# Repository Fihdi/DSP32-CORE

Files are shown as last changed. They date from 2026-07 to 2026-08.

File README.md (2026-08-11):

# DSP32-Core
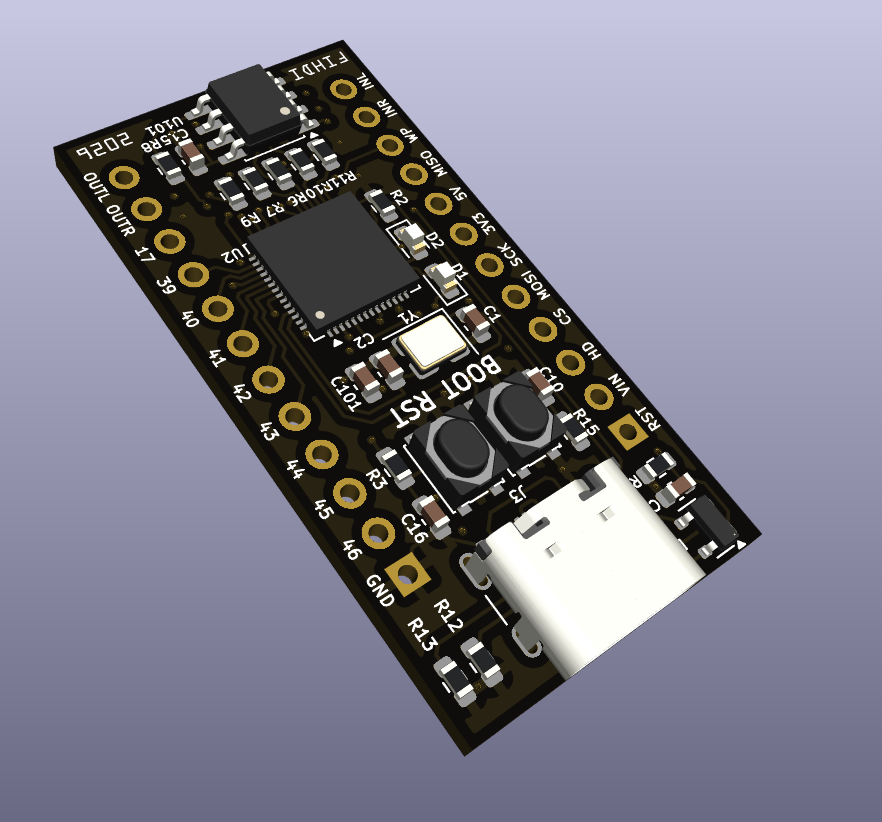
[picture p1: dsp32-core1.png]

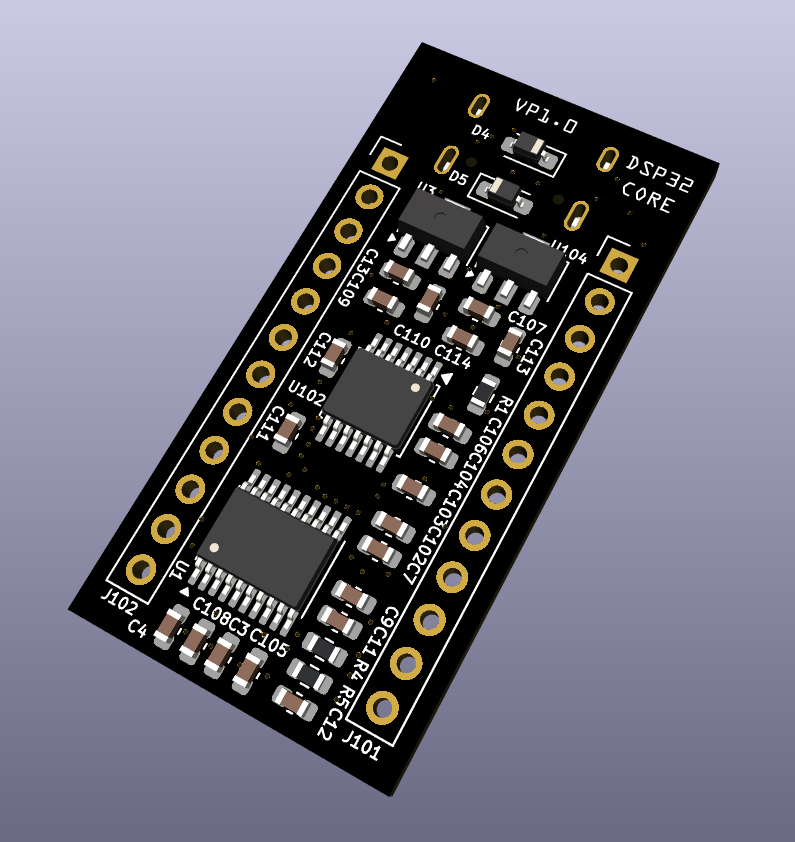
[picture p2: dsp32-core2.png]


DSP32-Core is a small (4cm x 2cm) audio development board based on the ESP32-S3. This board can be used as the core for digital music and audio applications involving synthesizers, samplers, digital effects, sequencers, etc. The SPI interface allows to connect an SD-card to the board and save and replay music and project settings.

# Features
+ Stereo audio in- and output
+ 3.3V and 5V voltage regulator
+ USB and SPI Interface
+ up to 15 GPIO pins
+ PCM1808 ADC
+ PCM5102 DAC.
# Pinout
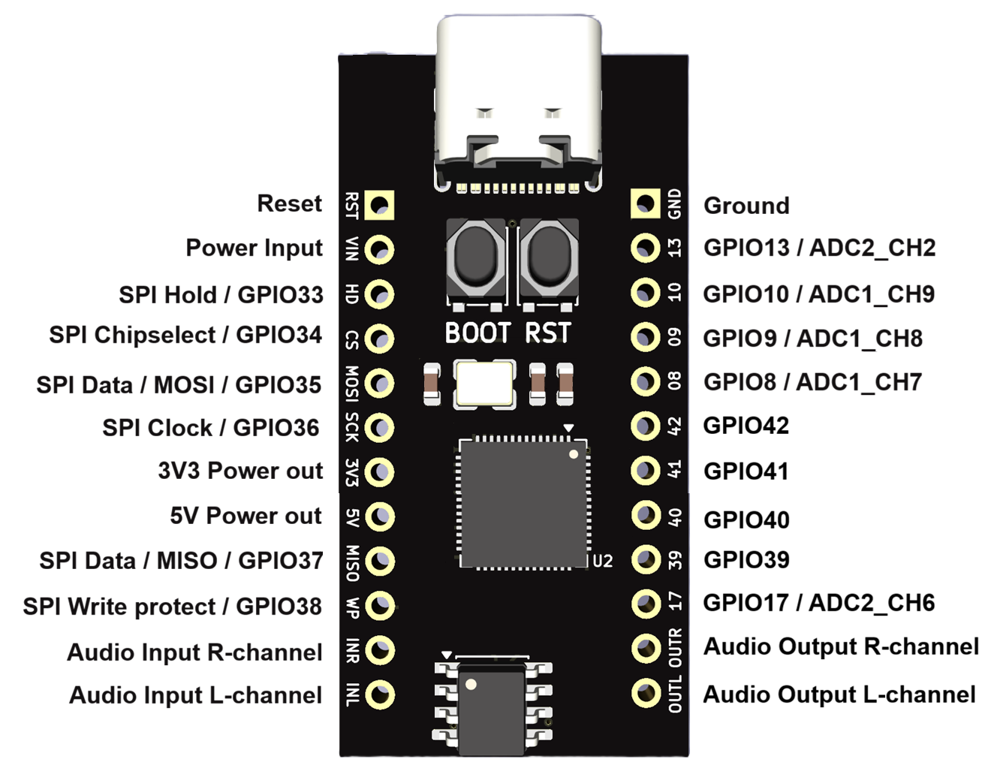
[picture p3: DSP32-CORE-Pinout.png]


PCB fabrication sponsored by [PCBWay](https://pcbway.com). Their excellent PCB assembly service allows the DSP32-CORE to be produced in with every component perfectly soldered. Simply upload the production files like gerbers, position and BOM files and receive your fully assembled audio development board. High PCB quality and good customer service throughout the process makes PCBWay a reliable partner.



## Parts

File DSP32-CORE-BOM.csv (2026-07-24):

Reference | Qty | Value | DNP | Exclude from BOM | Exclude from Board | Footprint | Datasheet
C1,C2 | 2 | 6pF |  |  |  | Capacitor_SMD:C_0603_1608Metric | ~
C3,C4,C13,C105,C107 | 5 | 2u2 |  |  |  | Capacitor_SMD:C_0603_1608Metric | ~
C7,C102,C103,C104 | 4 | 1u |  |  |  | Capacitor_SMD:C_0603_1608Metric | ~
C9,C10,C15,C16,C101,C106,C108,C109,C110,C111,C114 | 11 | 100n |  |  |  | Capacitor_SMD:C_0603_1608Metric | ~
C11,C12 | 2 | 2n2 |  |  |  | Capacitor_SMD:C_0603_1608Metric | ~
C14 | 1 | 4n7 |  |  |  | Capacitor_SMD:C_0603_1608Metric | ~
C112,C113 | 2 | 10u |  |  |  | Capacitor_SMD:C_0603_1608Metric | ~
D1,D2 | 2 | LED |  |  |  | LED_SMD:LED_0603_1608Metric | ~
D4,D5 | 2 | 1N4148 |  |  |  | Diode_SMD:D_SOD-323_HandSoldering | ~
D6 | 1 | PRTR5V0U2X |  |  |  | Package_TO_SOT_SMD:SOT-143 | https://assets.nexperia.com/documents/data-sheet/PRTR5V0U2X.pdf
J3 | 1 | USB_C_Receptacle |  |  |  | Connector_USB:USB_C_Receptacle_GCT_USB4105-xx-A_16P_TopMnt_Horizontal | https://www.usb.org/sites/default/files/documents/usb_type-c.zip
J101,J102 | 2 | Conn_01x12_Pin |  |  |  | Connector_PinHeader_2.54mm:PinHeader_1x12_P2.54mm_Vertical | ~
R1,R2 | 2 | 1k |  |  |  | Resistor_SMD:R_0603_1608Metric | ~
R3,R12,R13,R15 | 4 | 5k1 |  |  |  | Resistor_SMD:R_0603_1608Metric | ~
R4,R5 | 2 | 470R |  |  |  | Resistor_SMD:R_0603_1608Metric | ~
R6,R7,R8,R9,R10,R11 | 6 | 0R |  |  |  | Resistor_SMD:R_0603_1608Metric | ~
R14 | 1 | 1M |  |  |  | Resistor_SMD:R_0603_1608Metric | ~
SW1,SW2 | 2 | SW_Push |  |  |  | Button_Switch_SMD:SW_SPST_PTS810 | ~
U1 | 1 | PCM5102 |  |  |  | Package_SO:TSSOP-20_4.4x6.5mm_P0.65mm | http://www.ti.com/lit/ds/symlink/pcm5102.pdf
U2 | 1 | ESP32-S3 |  |  |  | Package_DFN_QFN:QFN-56-1EP_7x7mm_P0.4mm_EP4x4mm | https://www.espressif.com/sites/default/files/documentation/esp32-s3_datasheet_en.pdf
U3 | 1 | AMS1117-3.3 |  |  |  | Package_TO_SOT_SMD:SOT-89-3 | http://www.advanced-monolithic.com/pdf/ds1117.pdf
U101 | 1 | W25Q128JVS |  |  |  | Package_SO:SOIC-8_5.3x5.3mm_P1.27mm | https://www.winbond.com/resource-files/w25q128jv_dtr%20revc%2003272018%20plus.pdf
U102 | 1 | PCM1808 |  |  |  | Package_SO:TSSOP-14_4.4x5mm_P0.65mm
U104 | 1 | MC78L05_SOT89 |  |  |  | Package_TO_SOT_SMD:SOT-89-3 | https://www.onsemi.com/pub/Collateral/MC78L00A-D.PDF
Y1 | 1 | 40MHz |  |  |  | Crystal:Crystal_SMD_3225-4Pin_3.2x2.5mm | ~

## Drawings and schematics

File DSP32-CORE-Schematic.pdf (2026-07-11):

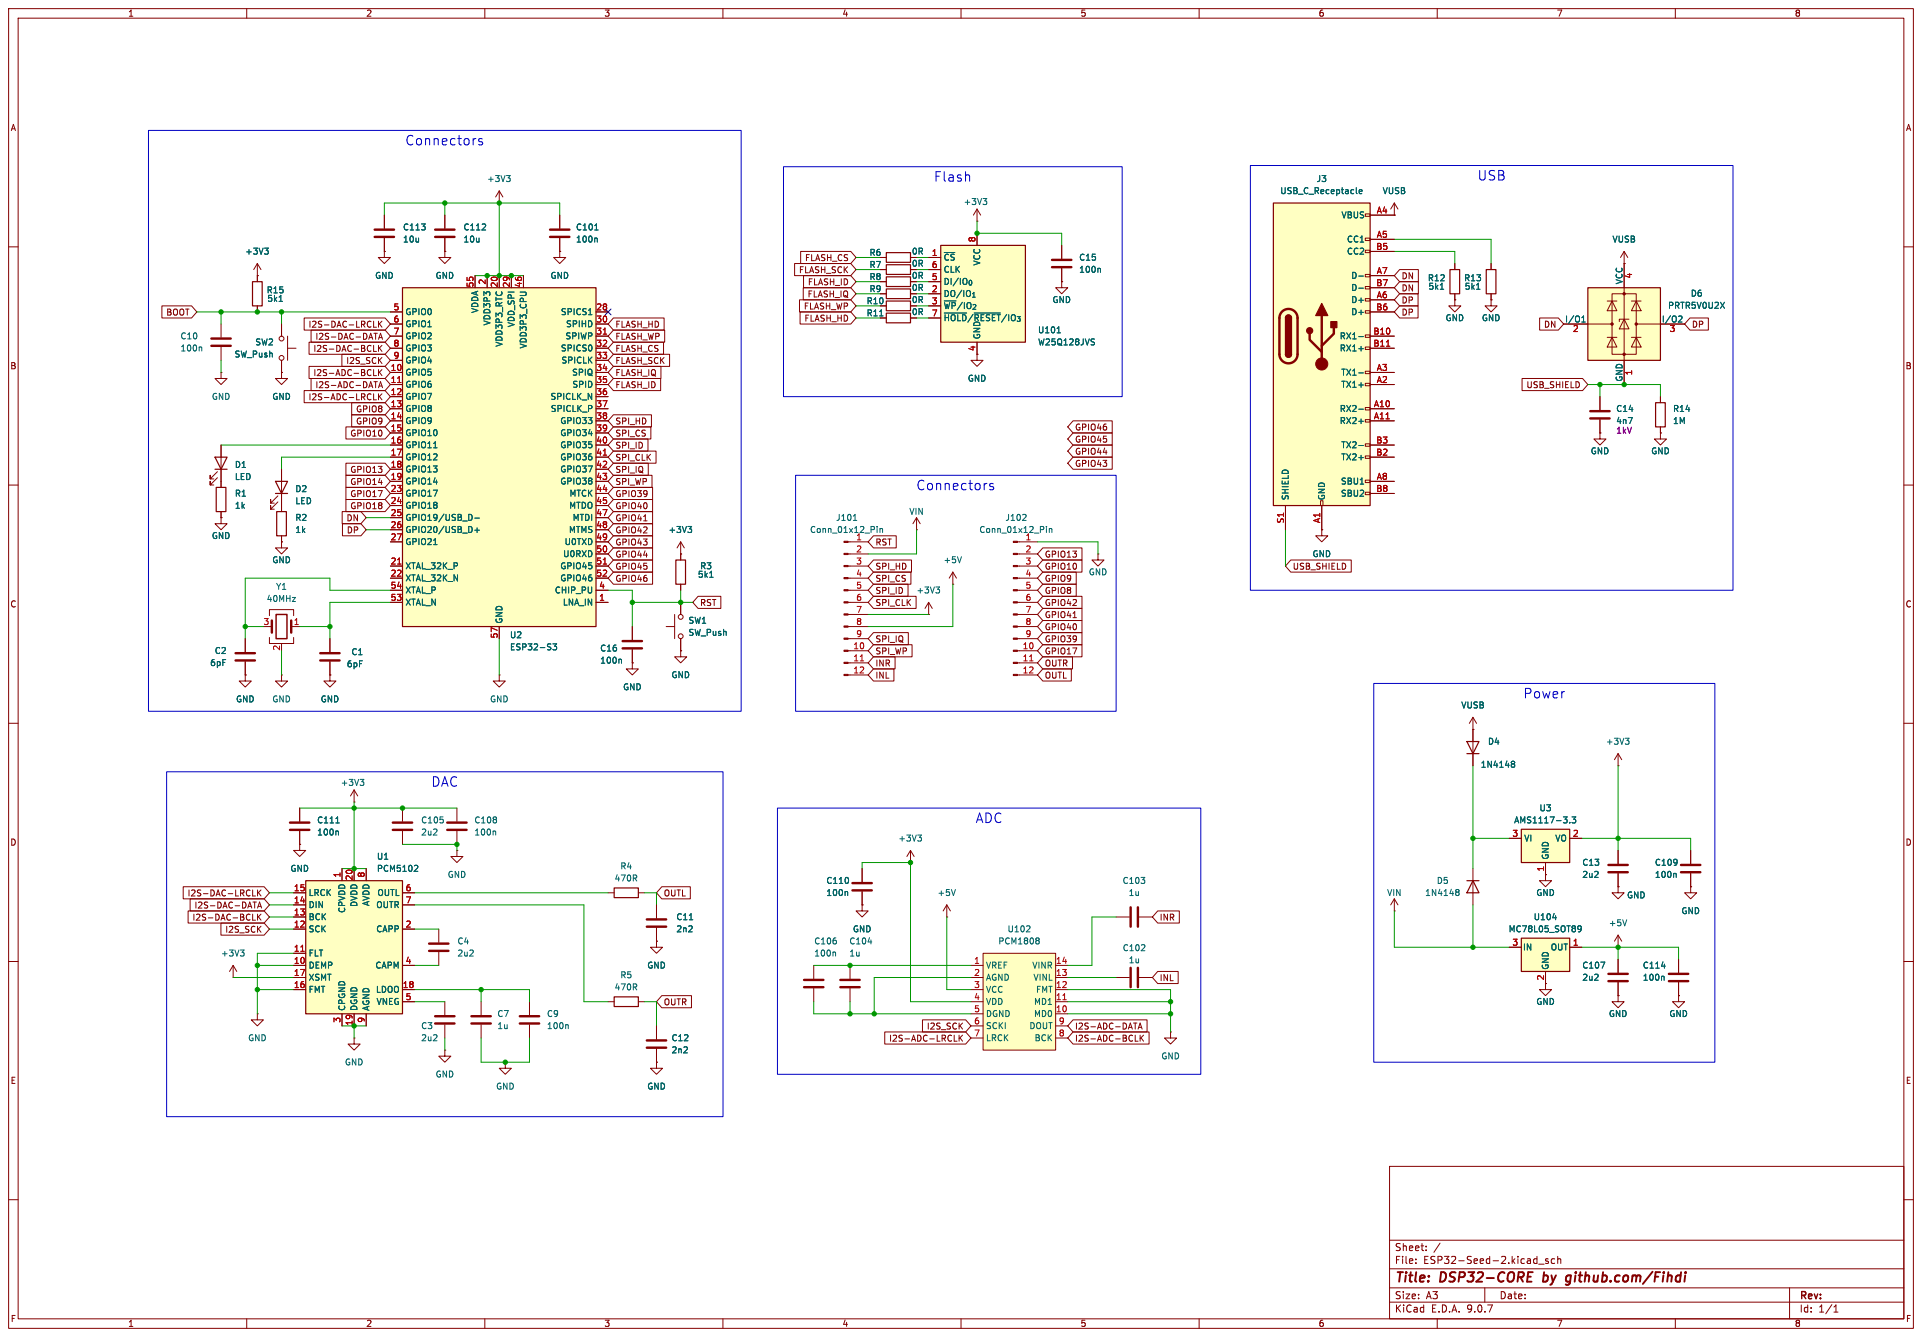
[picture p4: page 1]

2 VDD3P3_RTC 20 GND 57 VDD_SPI 29 VDD3P3_CPU 46 SPICS1 28 SPIHD 30 SPIWP 31 SPICS0 32 SPICLK 33 SPIQ 34 SPID 35 SPICLK_P 37 GPIO33 38 GPIO34 39 GPIO35 40 GPIO36 41 GPIO37 42 GPIO38 43 MTCK 44 MTDI 47 MTMS 48 U0TXD 49 U0RXD 50 GPIO46 52 CHIP_PU 4

9 OUTL 6 OUTR 7 CAPP 2 CAPM 4

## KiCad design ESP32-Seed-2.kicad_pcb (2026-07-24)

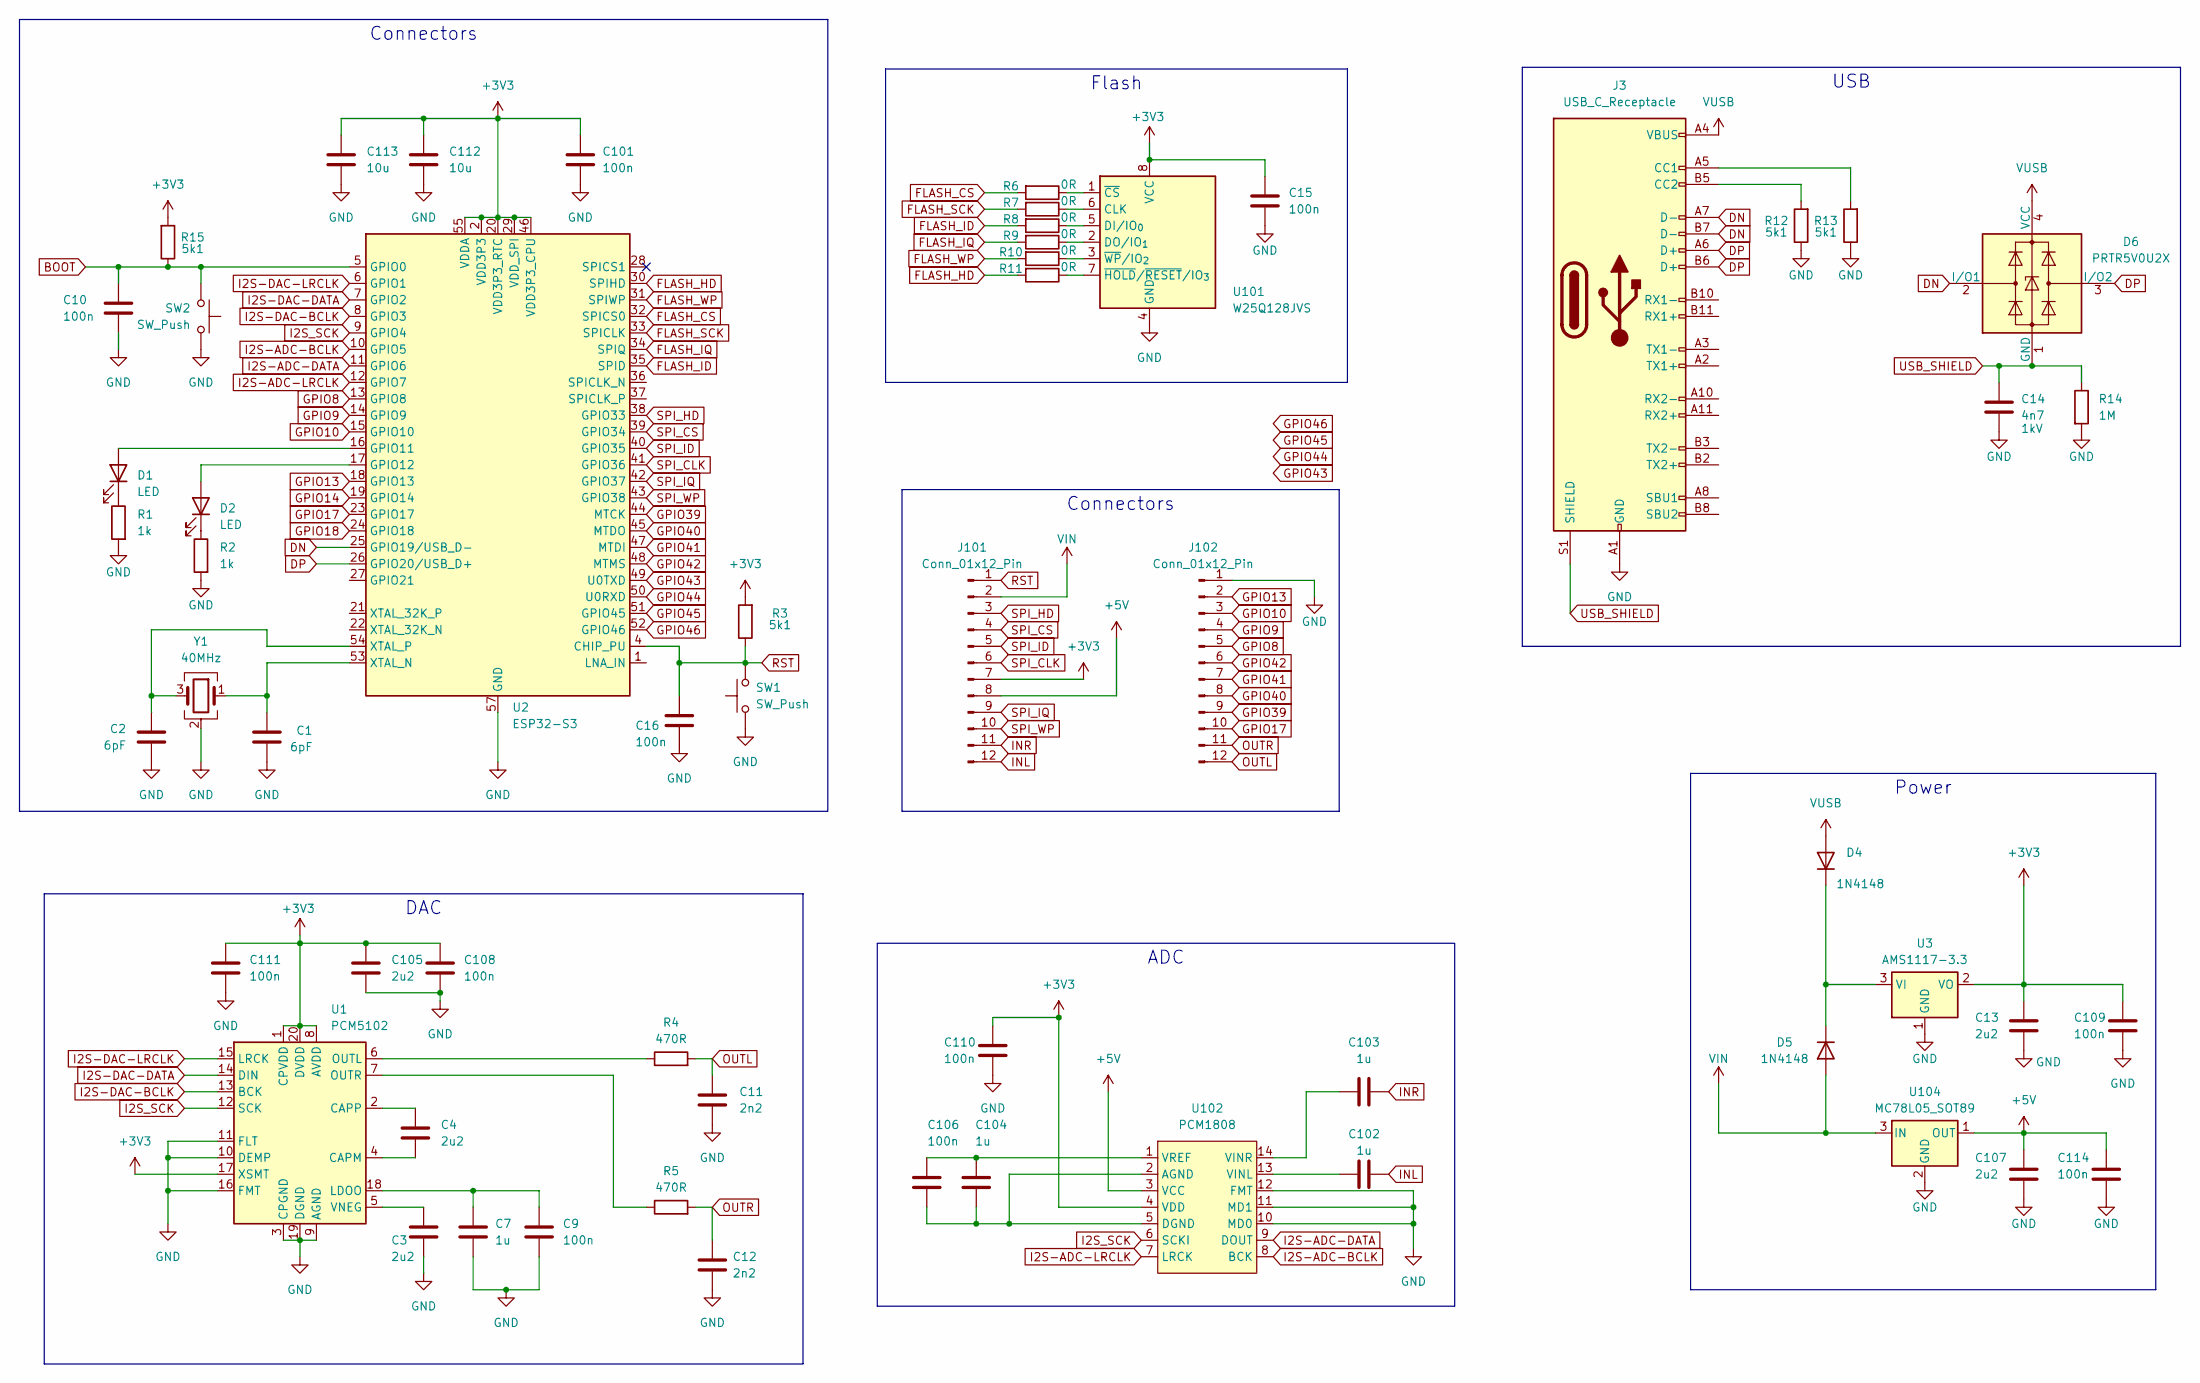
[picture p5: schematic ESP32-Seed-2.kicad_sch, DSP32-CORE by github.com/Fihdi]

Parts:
C1, C2: 6pF; C_0603_1608Metric
C3, C4, C13, C105, C107: 2u2; C_0603_1608Metric
C7, C102, C103, C104: 1u; C_0603_1608Metric
C9, C10, C15, C16, C101, C106, C108, C109, C110, C111, C114: 100n; C_0603_1608Metric
C11, C12: 2n2; C_0603_1608Metric
C14: 4n7; C_0603_1608Metric
C112, C113: 10u; C_0603_1608Metric
D1, D2: LED; LED_0603_1608Metric
D4, D5: 1N4148; D_SOD-323_HandSoldering
D6: PRTR5V0U2X; SOT-143
J3: USB_C_Receptacle; USB_C_Receptacle_GCT_USB4105-xx-A_16P_TopMnt_Horizontal
J101, J102: Conn_01x12_Pin; PinHeader_1x12_P2.54mm_Vertical
R1, R2: 1k; R_0603_1608Metric
R3, R12, R13, R15: 5k1; R_0603_1608Metric
R4, R5: 470R; R_0603_1608Metric
R6, R7, R8, R9, R10, R11: 0R; R_0603_1608Metric
R14: 1M; R_0603_1608Metric
SW1, SW2: SW_Push; SW_SPST_PTS810
U1: PCM5102; TSSOP-20_4.4x6.5mm_P0.65mm
U2: ESP32-S3; QFN-56-1EP_7x7mm_P0.4mm_EP4x4mm
U3: AMS1117-3.3; SOT-89-3
U101: W25Q128JVS; SOIC-8_5.3x5.3mm_P1.27mm
U102: PCM1808; TSSOP-14_4.4x5mm_P0.65mm
U104: MC78L05_SOT89; SOT-89-3
Y1: 40MHz; Crystal_SMD_3225-4Pin_3.2x2.5mm

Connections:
+3V3: C13.1, C15.1, C101.1, C105.1, C108.1, C109.1, C110.1, C111.1, C112.1, C113.1, J101.7, R3.2, R15.2, U1.1 (CPVDD), U1.8 (AVDD), U1.17 (XSMT), U1.20 (DVDD), U2.2 (VDD3P3), U2.3 (VDD3P3), U2.20 (VDD3P3_RTC), U2.29 (VDD_SPI), U2.46 (VDD3P3_CPU), U2.55 (VDDA), U2.56 (VDDA), U3.2 (VO), U101.8 (VCC), U102.4 (VDD)
+5V: C107.1, C114.1, J101.8, U102.3 (VCC), U104.1 (OUT)
BOOT: C10.1, R15.1, SW2.2, U2.5 (GPIO0)
DN: D6.2 (I/O1), J3.A7 (D-), J3.B7 (D-), U2.25 (GPIO19/USB_D-)
DP: D6.3 (I/O2), J3.A6 (D+), J3.B6 (D+), U2.26 (GPIO20/USB_D+)
FLASH_CS: R6.2, U2.32 (SPICS0)
FLASH_HD: R11.2, U2.30 (SPIHD)
FLASH_ID: R8.2, U2.35 (SPID)
FLASH_IQ: R9.2, U2.34 (SPIQ)
FLASH_SCK: R7.2, U2.33 (SPICLK)
FLASH_WP: R10.2, U2.31 (SPIWP)
GND: C1.2, C2.2, C3.2, C7.2, C9.2, C10.2, C11.2, C12.2, C13.2, C14.2, C15.2, C16.2, C101.2, C105.2, C107.2, C108.2, C109.2, C110.2, C111.2, C112.2, C113.2, C114.2, J3.A1 (GND), J3.A12 (GND), J3.B1 (GND), J3.B12 (GND), J102.1, R1.2, R2.2, R12.1, R13.1, R14.2, SW1.1, SW2.1, U1.3 (CPGND), U1.9 (AGND), U1.10 (DEMP), U1.11 (FLT), U1.16 (FMT), U1.19 (DGND), U2.57 (GND), U3.1 (GND), U101.4 (GND), U102.10 (MD0), U102.11 (MD1), U102.12 (FMT), U104.2 (GND), Y1.2 (G), Y1.4 (G)
GPIO8: J102.5, U2.13 (GPIO8)
GPIO9: J102.4, U2.14 (GPIO9)
GPIO10: J102.3, U2.15 (GPIO10)
GPIO13: J102.2, U2.18 (GPIO13)
GPIO14: U2.19 (GPIO14)
GPIO17: J102.10, U2.23 (GPIO17)
GPIO18: U2.24 (GPIO18)
GPIO39: J102.9, U2.44 (MTCK)
GPIO40: J102.8, U2.45 (MTDO)
GPIO41: J102.7, U2.47 (MTDI)
GPIO42: J102.6, U2.48 (MTMS)
GPIO43: U2.49 (U0TXD)
GPIO44: U2.50 (U0RXD)
GPIO45: U2.51 (GPIO45)
GPIO46: U2.52 (GPIO46)
I2S-ADC-BCLK: U2.10 (GPIO5), U102.8 (BCK)
I2S-ADC-DATA: U2.11 (GPIO6), U102.9 (DOUT)
I2S-ADC-LRCLK: U2.12 (GPIO7), U102.7 (LRCK)
I2S-DAC-BCLK: U1.13 (BCK), U2.8 (GPIO3)
I2S-DAC-DATA: U1.14 (DIN), U2.7 (GPIO2)
I2S-DAC-LRCLK: U1.15 (LRCK), U2.6 (GPIO1)
I2S_SCK: U1.12 (SCK), U2.9 (GPIO4), U102.6 (SCKI)
INL: C102.2, J101.12
INR: C103.2, J101.11
unnamed: D1.2 (A), U2.16 (GPIO11)
unnamed: D1.1 (K), R1.1
unnamed: D2.2 (A), U2.17 (GPIO12)
unnamed: D2.1 (K), R2.1
unnamed: D4.1 (K), D5.1 (K), U3.3 (VI)
unnamed: J3.A5 (CC1), R13.2
unnamed: J3.B5 (CC2), R12.2
unnamed: C4.2, U1.4 (CAPM)
unnamed: C4.1, U1.2 (CAPP)
unnamed: C7.1, C9.1, U1.18 (LDOO)
unnamed: R4.1, U1.6 (OUTL)
unnamed: R5.1, U1.7 (OUTR)
unnamed: C3.1, U1.5 (VNEG)
unnamed: C1.1, U2.53 (XTAL_N), Y1.1
unnamed: C2.1, U2.54 (XTAL_P), Y1.3
unnamed: R7.1, U101.6 (CLK)
unnamed: R8.1, U101.5 (DI/IO_{0})
unnamed: R9.1, U101.2 (DO/IO_{1})
unnamed: R6.1, U101.1 (~CS)
unnamed: R11.1, U101.7 (~HOLD/~RESET/IO_{3})
unnamed: R10.1, U101.3 (~WP/IO_{2})
unnamed: C104.2, C106.2, U102.2 (AGND), U102.5 (DGND)
unnamed: C102.1, U102.13 (VINL)
unnamed: C103.1, U102.14 (VINR)
unnamed: C104.1, C106.1, U102.1 (VREF)
OUTL: C11.1, J102.12, R4.2
OUTR: C12.1, J102.11, R5.2
RST: C16.1, J101.1, R3.1, SW1.2, U2.4 (CHIP_PU)
SPI_CLK: J101.6, U2.41 (GPIO36)
SPI_CS: J101.4, U2.39 (GPIO34)
SPI_HD: J101.3, U2.38 (GPIO33)
SPI_ID: J101.5, U2.40 (GPIO35)
SPI_IQ: J101.9, U2.42 (GPIO37)
SPI_WP: J101.10, U2.43 (GPIO38)
USB_SHIELD: C14.1, D6.1 (GND), J3.S1 (SHIELD), R14.1
VIN: D5.2 (A), J101.2, U104.3 (IN)
VUSB: D4.2 (A), D6.4 (VCC), J3.A4 (VBUS), J3.A9 (VBUS), J3.B4 (VBUS), J3.B9 (VBUS)

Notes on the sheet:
DAC
Connectors
Power
ADC
Flash
USB

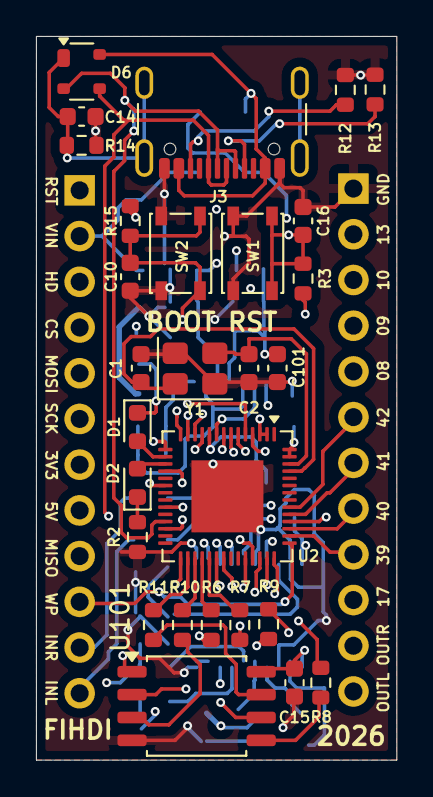
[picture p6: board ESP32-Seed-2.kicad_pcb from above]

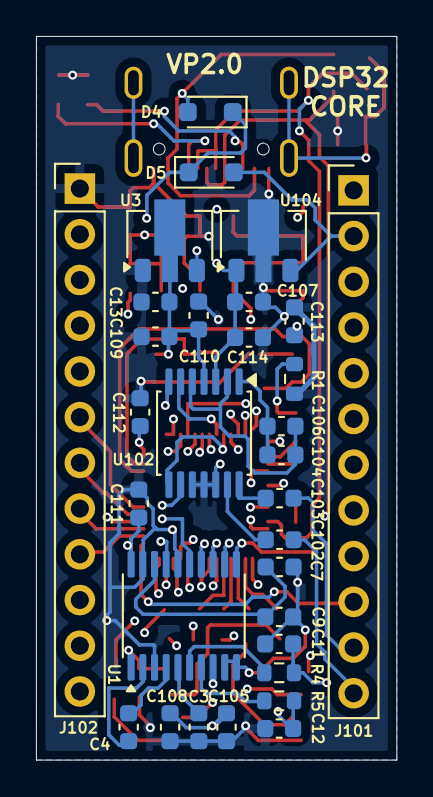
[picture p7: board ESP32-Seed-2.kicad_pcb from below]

Board: 4 copper layers, 20.0 x 40.2 mm, 59 parts (31 on the bottom side), 67 nets.
